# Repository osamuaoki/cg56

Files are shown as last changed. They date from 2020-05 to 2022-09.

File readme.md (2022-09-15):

# Grid Keyboard with 56 keys and its variants
<!---
vim:set tw=79 ts=4 sts=4 sw=4 et nosi filetype=markdown:
-->

This repo hosts data and some documents for my handwared keyboard projects. I
call this repository as cg56 which stands for Cartesian Grid Keyboard with 56
keys.  The corresponding keyboard name in my QMK source is cgc56 which stands
for Cartesian Grid Keyboard (compact) with 56 keys.  The longer name is chosen
to differentiate variants.

## Related memo in Japanese

There are more detailed memos in Japanese on how my hobby project proceeded
slowly since 2016. (Now 2022)  Its highlights are:

* https://osamuaoki.github.io/jp/2020/01/03/cg56-1/
* https://osamuaoki.github.io/jp/2021/12/11/atmega32u4-4/
* https://osamuaoki.github.io/jp/2022/02/07/blackpill-1/
* https://osamuaoki.github.io/jp/2022/03/15/home-mt/
* https://osamuaoki.github.io/jp/2022/09/01/blackpill-4/
* https://osamuaoki.github.io/jp/2022/09/09/home-mt2/ (review)

## Keyboard project history

* cg56: Cartesian Grid Keyboard with 56 keys (2016-2018)
    * NC laser cut MDF board (cut, stacked, glued, filed, and painted)
    * 56 keys (14 x 4)
    * ATMega32u4 x 1 (teensy 2 compatible board with nanoBoot HID bootloader)
    * Project stalled and case is repurposed for the next cgc56 project.
    * [NC CAD data (dxf) is in this repository](cad/cg56.dxf)
    * [NC CAD data (pdf) is in this repository](cad/MDF_CUT_grid56w.pdf)
    * See [ATmega32u4 (rev01)](rev01.md) -- never made -- for details of around MCU and shape of key matrix.
    * See [Key matrix for cg56 and cgc56](cg56.md) for electrical details of key matrix.

* cgc56: Cartesian Grid Keyboard (compact) with 56 keys (2022/Feb -- initial)
    * NC laser cut MDF board
      * recycled case taken from stalled cg56
      * Add independent USB connector board.
      * internal space of already built case was enlarged by mechanically grinding the MDF board
    * 56 keys (14 x 4)
    * AT90USB1286 x 1
      * Teensy 2++ compatible circuit board with LUFA HID bootloader
    * initial cgc56 front view with OEM keycaps
      <br>
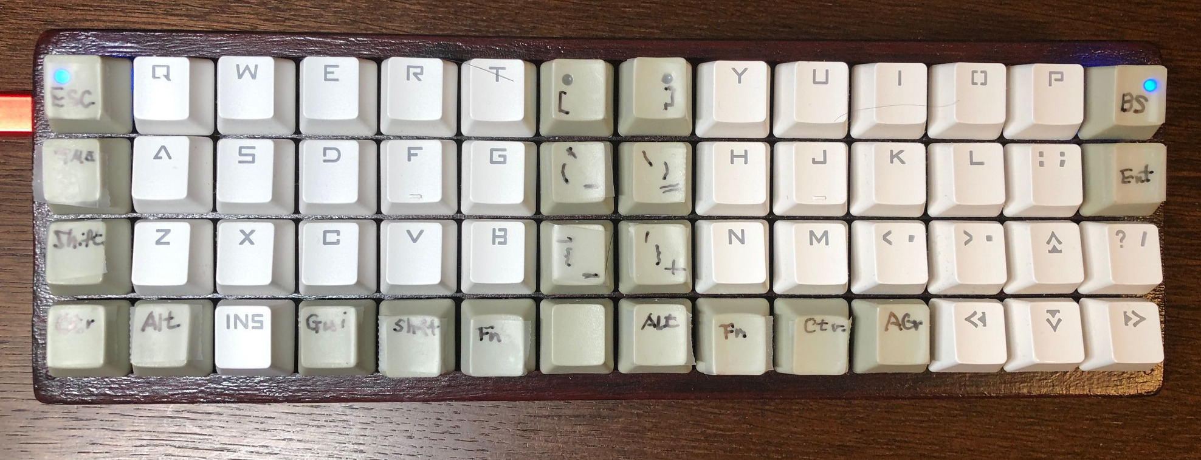
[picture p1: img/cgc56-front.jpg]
      
    * cgc56 side view with OEM key caps
      <br>
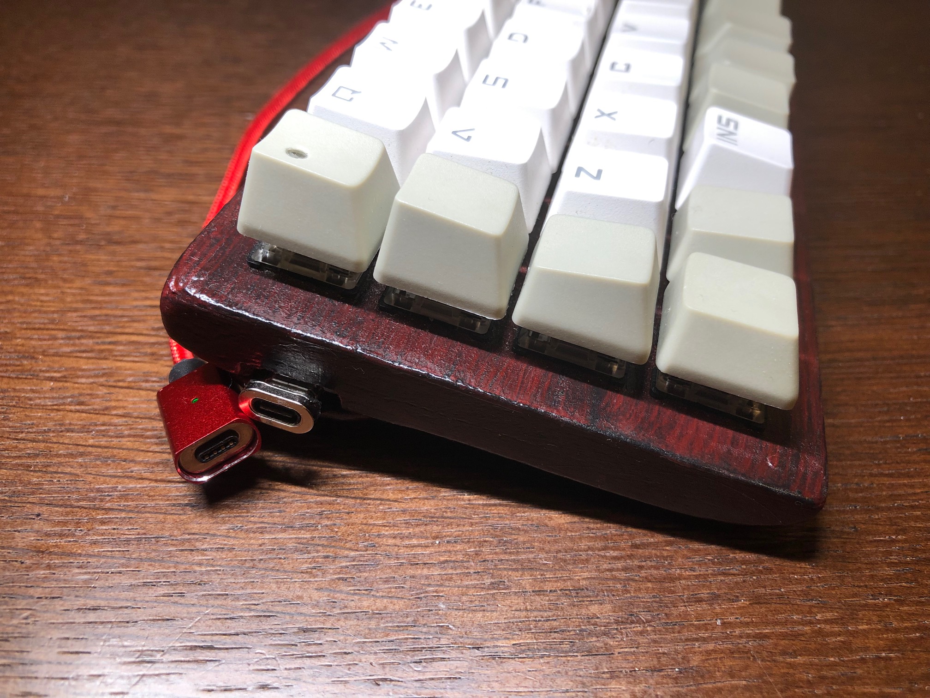
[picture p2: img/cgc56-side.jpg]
      
    * See [AT90USB1286 (rev02)](rev02.md) for details of around MCU and shape of key matrix.
    * See [Key matrix for cg56 and cgc56](cg56.md) for electrical details of key matrix.
    * See [cgc56 in Osamu's QMK fork with osamu1 branch](https://github.com/osamuaoki/qmk_firmware/blob/osamu1/keyboards/cgc56/keymaps/default/keymap.c)  -- this is not maintained.
    * See [extra photo for cg56](photo-cg56.md)

* **cgc56**: Cartesian Grid Keyboard (compact) with 56 keys (2022/Sep)
    * Keycaps are changed to DSA.
      * The front edge of red keycaps for the thumb are rounded using the sand
        paper.
      * keymaps are optimized (now "pico" is used)
    * 56 keys (14 x 4) -- no change
    * AT90USB1286 x 1 -- no change
      <br>
    * updated cgc56 top view with DSA keycaps for the pico keymap
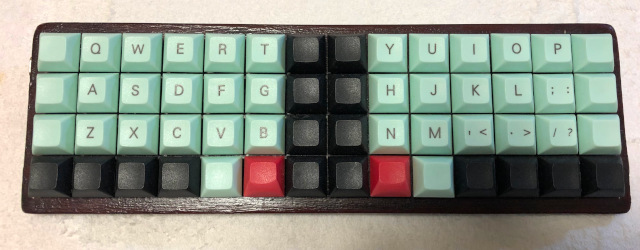
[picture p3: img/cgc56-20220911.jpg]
cgc56 new
      
    * See [cgc56 in Osamu's QMK fork with osamu1 branch](https://github.com/osamuaoki/qmk_firmware/blob/osamu1/keyboards/cgc56/keymaps/pico/keymap.c) -- this is maintained.

* cgg56: Cartesian Grid Keyboard (gap) with 56 keys (2022/Feb)
    * Hand cut and glued 5mm x 5mm plastic bars
    * 56 keys (14 x 4) + X-Y joystick (resistive)
    * STM32F411CE x 1 (WeAct Blackpill)
    * cgg56 front view with OEM keycaps
      <br>
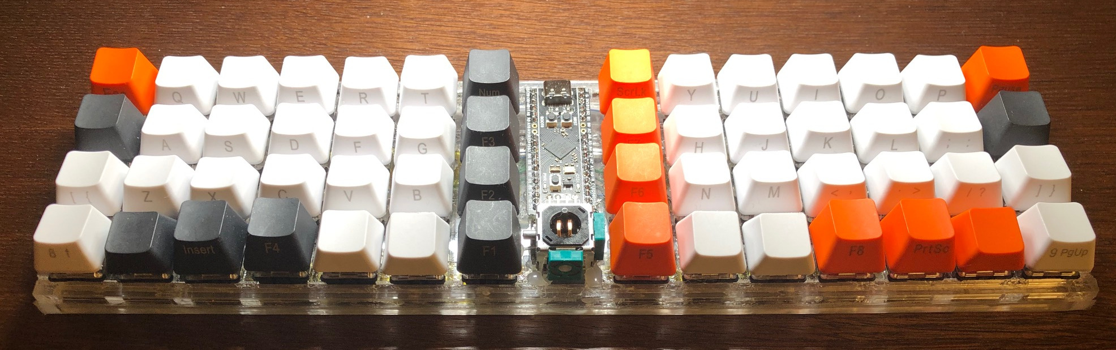
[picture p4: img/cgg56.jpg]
      
    * See [STM32F411CEU6 (rev03)](rev03.md) for details of around MCU and shape of key matrix.
    * See [Key matrix for gcg56](cgg56.md) for electrical details of key matrix.
    * See [STM32F411CE (1)](https://osamuaoki.github.io/jp/2022/02/07/blackpill-1/) (Japanese) for cgg56
    * See [cgg56 in Osamu's QMK fork with osamu1 branch](https://github.com/osamuaoki/qmk_firmware/blob/osamu1/keyboards/cgg56/keymaps/pico/keymap.c) -- this is not maintained.

* cgs58: Cartesian Grid Keyboard (split) with 58 keys
    * Hand cut and glued 5mm x 5mm plastic bars
      * recycled case taken from cgg56
      * hack sawed cgg56 at the center and extended with glued 5mm x 5mm plastic bars
    * 58 keys ((7 x 4 + 1) x 2)
    * STM32F411CE x 2 (WeAct Blackpill)
    * cgs58 front view with OEM keycaps
      <br>
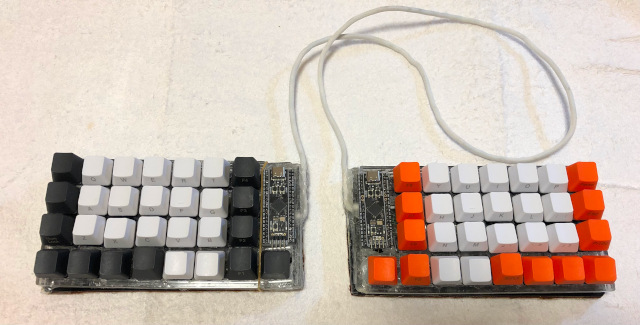
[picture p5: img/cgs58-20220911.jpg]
      
    * This is 16U wide and can't fit into A4 size case. (Too big!)
    * See [STM32F411CE (4)](https://osamuaoki.github.io/jp/2022/09/01/blackpill-4/) (Japanese) for the modification from cgg56 to cgs58.
    * See [cgs58 in Osamu's QMK fork with osamu1 branch](https://github.com/osamuaoki/qmk_firmware/blob/osamu1/keyboards/cgs58/keymaps/pico/keymap.c) -- this is not maintained.

* **cgs50**: Cartesian Grid Keyboard (split) with 50 keys (2022/Sep)
    * Hand cut and glued 5mm x 5mm plastic bars
      * recycled case taken from cgs58
      * hack sawed cgs58 at the both ends and glued 5mm x 5mm plastic bars to close the ends.
    * 50 keys ((6 x 4 + 1) x 2)
    * STM32F411CE x 2 (WeAct Blackpill)
    * cgs50 front view with OEM keycaps
      <br>
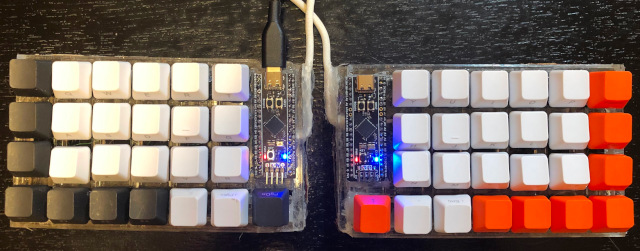
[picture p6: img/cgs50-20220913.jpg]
      
    * This is 14U wide and can fit into A4 size case.
    * Just cut both ends and removed wiring around them.
    * See [cgs58 in Osamu's QMK fork with osamu1 branch](https://github.com/osamuaoki/qmk_firmware/blob/osamu1/keyboards/cgs50/keymaps/pico/keymap.c) -- this is maintained.

## Background

I felt pain between my right ring and pinkie fingers.  I wondered why I suffer
such a pain since I type very slowly and my slow typing should be very low
stress on my fingers.  I then realized that I stretch my pinkie finger to reach
"Enter" and "BS" keys which are away from the home position of my right pinkie
finger.  Situation with laptop JIS (JA) keyboard which I now use regularly is
worse than ANSI (US) keyboard since the "Enter" key is 3 steps away.

Even on the ANSI (US) 104 keyboard, my weak right pinkie finger is covering 20
keys while even my capable right pointer finger covers only 9 keys and most
other fingers cover less.  Although these extra keys typed by my right pinkie
finger are mostly rarely typed keys, these are used more for coding programs.

Also, un-natural staggered key arrangement is another annoyance to twist my
body.  The default positions of hands seem to be too close to each other for me
to keep my good posture.

Hmmm... I need to keep my posture right while keeping my fingers relaxed.

## Design Policy

The following design policy is deployed to design a custom keyboard.

* Use only FREE software (DFSG compliant)
* Compact, simple, and natural design
    * Compact enough to be portable: 56 keys (4 rows x 14 columns) or less
    * Keys in the linear orthogonal Cartesian grid coordinate positions
    * Never move pinkie fingers more than one column away.
    * Never move pointer fingers more than two column away.
    * Keep left and right fingers separated enough.
    * All ASCII codes are accessible without moving the palm position.
* Least leaning pain key-position design
    * Minimal key-position change from the standard ANSI (US).
    * BS at the right top corner.
    * ESC in place of CapsLock position (yay, Vim).
    * Keep F and J keys separated with 4 keys (or more) instead of standard 2 keys.
    * Move non-shift non-alphabet symbols to the center if you ever have them.
    * Layer changing Fn keys in thumb home positions to offer practically all ANSI 104 (JIS 106?) keys.
        * Function keys (F1-F12) are in the top row with Fn.
        * Number keys are in the high-middle row with Fn.
        * Odd keys are in the low-middle row with Fn
    * SPACE should be at the thumb position of the bottom row.
    * Cursor keys are in the hard to reach part of the bottom row if you ever have them.
    * Topography effects to find finger home positions
      * Use key cap height differences with the OEM keycaps.
      * Use mechanically modified thumb keys with DSA keycaps.
* Keep it simple and cheap (It's my first custom keyboard!)
    * Use commodity electronics parts (as much)
      * Use the laser cut MDF board as the case (if needed)
      * Use 5mm x 5mm plastic bars and glue purchased at the local hardware
        shop.
    * Use only 1U key caps (=no stabilizer)
    * No PCB but lots of messy hand wiring :-)

## What's different

You may wonder what's different from other so called "ortholinear" keyboards
such as plank.

* Enough distance between left and right hands. (2U->4U)
* 7 columns per one side instead of 6 columns such as
  [plunk](https://olkb.com/planck) to minimize key position irregularities.
* Single piece compact design without irregular shape vs.
  [Ergo42](https://bit-trade-one.co.jp/selfmadekb/adskb42/) and
  [ErgoTravel](https://github.com/jpconstantineau/ErgoTravel) .
* Extensive use of hot-melt glue which should also function as noise dumper.

Yah, it's not much different in basic hardware design ... it's mostly a taste
difference.

As for the pinkie finger stress, the home row mod keymap really helped.

## Design thoughts

Here, ASCII art versions of basic design implementation ideas are provided.

### Case Design for cg56

Case with orthogonal key switch matrix design with enough space for thumb
finger coverage and without stressing pinkie finger.

* Primary positions: `###` (home positions)
* Almost primary positions: `.#.` (almost home positions)
* Adjacent positions: `...` (easy to reach minimum movement positions)

```
┌───┬───┬───┬───┬───┬───┬───┬───┬───┬───┬───┬───┬───┬───┐
│   │...│...│...│...│...│   │   │...│...│...│...│...│   │
├───┼───┼───┼───┼───┼───┼───┼───┼───┼───┼───┼───┼───┼───┤
│...│###│###│###│###│...│...│...│...│###│###│###│###│...│
├───┼───┼───┼───┼───┼───┼───┼───┼───┼───┼───┼───┼───┼───┤
│...│.#.│...│...│.#.│...│...│...│...│.#.│...│...│.#.│...│
├───┼───┼───┼───┼───┼───┼───┼───┼───┼───┼───┼───┼───┼───┤
│...│...│   │   │...│###│...│...│###│...│   │   │...│...│
└───┴───┴───┴───┴───┴───┴───┴───┴───┴───┴───┴───┴───┴───┘
```

### Key Assignment

Use least surprise design based on the standard QWERTY-keyboard.

Here is an example of key assignment.

Initial thought:
```
default
┌───┬───┬───┬───┬───┬───┬───┬───┬───┬───┬───┬───┬───┬───┐
│TAB│ q │ w │ e │ r │ t │ [ │ ] │ y │ u │ i │ o │ p │BS │
├───┼───┼───┼───┼───┼───┼───┼───┼───┼───┼───┼───┼───┼───┤
│ESC│ a │ s │ d │ f │ g │ ` │ \ │ h │ j │ k │ l │ ; │ ' │
├───┼───┼───┼───┼───┼───┼───┼───┼───┼───┼───┼───┼───┼───┤
│Sft│ z │ x │ c │ v │ b │***│***│ n │ m │ , │ . │ / │Sft│
├───┼───┼───┼───┼───┼───┼───┼───┼───┼───┼───┼───┼───┼───┤
│Ctr│Alt│ ↑ │ ↓ │Gui│Fn │Spc│Ent│Fn │App│ ← │ → │Alt│Ctr│
└───┴───┴───┴───┴───┴───┴───┴───┴───┴───┴───┴───┴───┴───┘

Fn-pressed
┌───┬───┬───┬───┬───┬───┬───┬───┬───┬───┬───┬───┬───┬───┐
│Prt│F1 │F2 │F3 │F4 │F5 │F11│F12│F6 │F7 │F8 │F9 │F10│SL │
├───┼───┼───┼───┼───┼───┼───┼───┼───┼───┼───┼───┼───┼───┤
│Cap│ 1 │ 2 │ 3 │ 4 │ 5 │ - │ = │ 6 │ 7 │ 8 │ 9 │ 0 │PB │
├───┼───┼───┼───┼───┼───┼───┼───┼───┼───┼───┼───┼───┼───┤
│___│***│***│***│***│***│***│***│***│***│***│***│***│___│
├───┼───┼───┼───┼───┼───┼───┼───┼───┼───┼───┼───┼───┼───┤
│___│___│Hom│End│Alt│___│Ins│Del│___│Ctl│PgU│PgD│___│___│
└───┴───┴───┴───┴───┴───┴───┴───┴───┴───┴───┴───┴───┴───┘
```

[Current QMK setting: (2022/Sep)](https://github.com/osamuaoki/qmk_firmware/blob/osamu1/keyboards/cgc56/keymaps/pico/keymap.c)
 -- with many tap-hold dual function keys.
```
0th layer: Normal tap (Essential stable keys only)
┌───┬───┬───┬───┬───┬───┬───┬───┬───┬───┬───┬───┬───┬───┐
│Tab│ Q │ W │ E │ R │ T │   │   │ Y │ U │ I │ O │ P │BS │
├───┼───┼───┼───┼───┼───┼───┼───┼───┼───┼───┼───┼───┼───┤
│Esc│ A │ S │ D │ F │ G │   │   │ H │ J │ K │ L │ ; │Ent│
├───┼───┼───┼───┼───┼───┼───┼───┼───┼───┼───┼───┼───┼───┤
│Mut│ Z │ X │ C │ V │ B │   │   │ N │ M │ , │ . │ / │Psc│
├───┼───┼───┼───┼───┼───┼───┼───┼───┼───┼───┼───┼───┼───┤
│   │   │   │   │MUH│Spc│   │   │Spc│HEN│   │   │   │   │
└───┴───┴───┴───┴───┴───┴───┴───┴───┴───┴───┴───┴───┴───┘

0th layer: Normal hold (MOD and LAYER keys)
┌───┬───┬───┬───┬───┬───┬───┬───┬───┬───┬───┬───┬───┬───┐
│   │   │   │   │   │   │   │   │   │   │   │   │   │   │
├───┼───┼───┼───┼───┼───┼───┼───┼───┼───┼───┼───┼───┼───┤
│Ctl│Sft│Crl│Alt│Gui│Agr│   │   │Agr│Gui│Alt│Ctl│Sft│   │
├───┼───┼───┼───┼───┼───┼───┼───┼───┼───┼───┼───┼───┼───┤
│Sft│   │   │Gui│MO2│   │   │   │   │   │   │   │   │Sft│
├───┼───┼───┼───┼───┼───┼───┼───┼───┼───┼───┼───┼───┼───┤
│   │   │   │   │   │   │   │   │   │   │   │   │   │   │
└───┴───┴───┴───┴───┴───┴───┴───┴───┴───┴───┴───┴───┴───┘

1st layer: activate with one Fn-key (= space key) pressed as hold
┌───┬───┬───┬───┬───┬───┬───┬───┬───┬───┬───┬───┬───┬───┐
│F11│F1 │F2 │F3 │F4 │F5 │   │   │F6 │F7 │F8 │F9 │F10│F12│
├───┼───┼───┼───┼───┼───┼───┼───┼───┼───┼───┼───┼───┼───┤
│Cap│ 1 │ 2 │ 3 │ 4 │ 5 │   │   │ 6 │ 7 │ 8 │ 9 │ 0 │App│
├───┼───┼───┼───┼───┼───┼───┼───┼───┼───┼───┼───┼───┼───┤
│   │ ` │   │   │ - │ = │   │   │ { │ } │ \ │   │ ' │LL2│
├───┼───┼───┼───┼───┼───┼───┼───┼───┼───┼───┼───┼───┼───┤
│   │   │   │   │   │vvv│   │   │vvv│KAN│   │   │   │   │
└───┴───┴───┴───┴───┴───┴───┴───┴───┴───┴───┴───┴───┴───┘

```
Please note:

* "shift-pressed" causes the normal shift conversion
* Missing function keys are generated by Fn-pressed Q-row keys.
* Missing number row keys are generated by Fn-pressed A-row keys.
* Missing outlier keys are generated by Fn-pressed Z-row keys.
* Let's worry about details later when in QMK firmware.
* Actual key layout will be experimentally determined.
  * 2nd layer: cursor
  * 3rd layer: ten-keys
  * 4th layer: mouse keys and system control

### Keyboard Topography (Type 1)

OEM 1U Key cap are used as below to offer optimal topography.

```
┌───┬───┬───┬───┬───┬───┬───┬───┬───┬───┬───┬───┬───┬───┐
│*1 │ Q │ Q │ Q │ Q │ Q │*1 │ 1*│ Q │ Q │ Q │ Q │ Q │ 1*│
├───┼───┼───┼───┼───┼───┼───┼───┼───┼───┼───┼───┼───┼───┤
│ 1 │_A_│_A_│_A_│_A_│ A │ 1 │ 1 │ A │_A_│_A_│_A_│_A_│ 1 │
├───┼───┼───┼───┼───┼───┼───┼───┼───┼───┼───┼───┼───┼───┤
│ Z │ Z │ Z │ Z │ Z │ Z │ 1 │ 1 │ Z │ Z │ Z │ Z │ Z │ Z │
├───┼───┼───┼───┼───┼───┼───┼───┼───┼───┼───┼───┼───┼───┤
│ A │ Z │ R │ R │ 1 │_Q_│ 1 │ 1 │_Q_│ 1 │ R │ R │ Z │ A │
└───┴───┴───┴───┴───┴───┴───┴───┴───┴───┴───┴───┴───┴───┘
 1:   1-row type
 Q:   Q-row type
 A:   A-row type
 Z:   Z-row type
 R:   Arrow-keys inserted upside down
 _ _: home position
 *:   LED position (outside is RED LED)
```

With the height difference to the adjacent keys, thumb and pinkie fingers
should have easier time to feel its home position.  (I may change height
combination later.)

Also by deploying higher keys (1-row type) for far-away keys, you can type
these keys by pressing their side faces.  They may not be bigger but are
easy to be reached.

### Keyboard Topography (Type 2)

Alternatively, DSA key tops may be used.

For that, I thought that modifying some keys with soft UV-resin or
crazy-glue+baking-soda may be interesting options to create topography.

I ended up grinding off front edge of thumb keys.

## Sitalled side project -- QWFRTY layout

**QWFRTY** layout was investigated as a minimal learning stress alternative layout but it was not so good.

* **QWFRTY** moves only 11-keys from the standard QWERTY.  Almost all short-cuts stay in place.
* **QWFRTY** encourages alternating hand typing like DVORAK by having all vowel characters on one side.  This should be lower stress.
  **QWFRTY** doesn't trash the user experience under Vim.  `hjkl`-keys are clustered as inverse-T making it even better than QWFRTY.

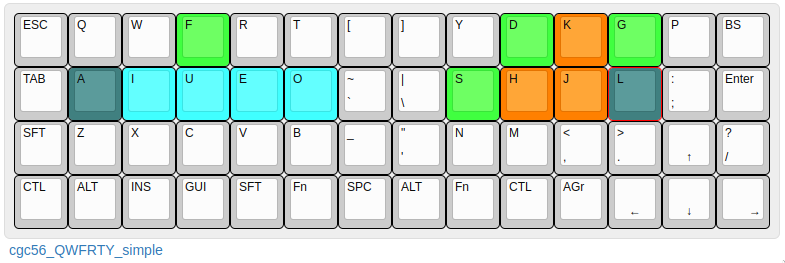
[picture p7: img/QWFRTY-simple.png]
QWFRTY


See https://osamuaoki.github.io/jp/2022/02/14/qwfrty/ (Japanese)

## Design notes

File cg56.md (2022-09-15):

# Key matrix for cg56 and cgc56
<!---
vim:set tw=79 ts=4 sts=4 sw=4 et nosi filetype=markdown:
-->

## Physical and Electrical Key Positions

The electric wiring column and row positions are described as below in
"Column/Row" order in the physical key positions.

Please note:
* Physical matrix: 4 rows * 14 columns
* Electrical matrix: 8 rows * 7 columns

This allows to scan 54 keys only with 15 pins.

### Top view

This top view can be used for software key address configuration.

```
 Q-side (Teensy)                          P-side (Speaker)
 ┌───┬───┬───┬───┬───┬───┬───┬───┬───┬───┬───┬───┬───┬───┐
 │0/0│1/0│2/0│3/0│4/0│5/0│6/0│0/1│1/1│2/1│3/1│4/1│5/1│6/1│
 ├───┼───┼───┼───┼───┼───┼───┼───┼───┼───┼───┼───┼───┼───┤
 │0/2│1/2│2/2│3/2│4/2│5/2│6/2│0/3│1/3│2/3│3/3│4/3│5/3│6/3│
 ├───┼───┼───┼───┼───┼───┼───┼───┼───┼───┼───┼───┼───┼───┤
 │0/4│1/4│2/4│3/4│4/4│5/4│6/4│0/5│1/5│2/5│3/5│4/5│5/5│6/5│
 ├───┼───┼───┼───┼───┼───┼───┼───┼───┼───┼───┼───┼───┼───┤
 │0/6│1/6│2/6│3/6│4/6│5/6│6/6│0/7│1/7│2/7│3/7│4/7│5/7│6/7│
 └───┴───┴───┴───┴───┴───┴───┴───┴───┴───┴───┴───┴───┴───┘
```

This is useful view for writing software for the key input conversion.

### Bottom view

This bottom view can be used for wiring key switches.

```
 P-side (Speaker)                         Q-side (Teensy)
 ┌───┬───┬───┬───┬───┬───┬───┬───┬───┬───┬───┬───┬───┬───┐
 │6/1│5/1│4/1│3/1│2/1│1/1│0/1│6/0│5/0│4/0│3/0│2/0│1/0│0/0│
 ├───┼───┼───┼───┼───┼───┼───┼───┼───┼───┼───┼───┼───┼───┤
 │6/3│5/3│4/3│3/3│2/3│1/3│0/3│6/2│5/2│4/2│3/2│2/2│1/2│0/2│
 ├───┼───┼───┼───┼───┼───┼───┼───┼───┼───┼───┼───┼───┼───┤
 │6/5│5/5│4/5│3/5│2/5│1/5│0/5│6/4│5/4│4/4│3/4│2/4│1/4│0/4│
 ├───┼───┼───┼───┼───┼───┼───┼───┼───┼───┼───┼───┼───┼───┤
 │6/7│5/7│4/7│3/7│2/7│1/7│0/7│6/6│5/6│4/6│3/6│2/6│1/6│0/6│
 └───┴───┴───┴───┴───┴───┴───┴───┴───┴───┴───┴───┴───┴───┘
```

This is useful view for wiring and building the hardware.

## Wiring of Switches and LEDs

This section always uses bottom view unless otherwise noted.

### Global simplified view of wiring

Here is a global simplified view of wiring of switches and LEDs (bottom view):

```
   P-side (Speaker)                                  Q-side (Teensy)

    LED4                      LED3  LED2                       LED1
    RCB                        RCB  RCB                         RCB

    C6  C5  C4  C3  C2  C1  C0            C6  C5  C4  C3  C2  C1  C0
    |   |   |   |   |   |   |             |   |   |   |   |   |   |
    S---S---S---S---S---S---S-- R1  R0  --S---S---S---S---S---S---S
    |   |   |   |   |   |   |             |   |   |   |   |   |   |
    S---S---S---S---S---S---S-- R3  R2  --S---S---S---S---S---S---S
    |   |   |   |   |   |   |             |   |   |   |   |   |   |
    S---S---S---S---S---S---S-- R5  R4  --S---S---S---S---S---S---S
    |   |   |   |   |   |   |             |   |   |   |   |   |   |
    S---S---S---S---S---S---S-- R7  R6  --S---S---S---S---S---S---S

```

Here:
* "+" indicates contacting cross
* "C" indicates no contact over cross
* "S" indicates switch and diode connect cross wire combination
* 2 wires for each column

### Key switches, LEDs, CRDs, Diodes and Speaker (Bottom view)

Insert [2 color LED](img/OSRB3132A.png) as below to the key switches (Bottom view)

```
 6/1, 0/1 switches          5/1, 4/1, 3/1, 2/1, 5/0, 4,0, 3/0, 2/0, 1/0,
                            6/3, 5/3, ..., 1/3, 6/2, 5/2, ..., 1/2, 0/2,
                            6/5, 5/5, ..., 1/5, 6/4, 5/4, ..., 1/4, 0/4
                            switches
  LED  LED  LED                  COL
  R    C    B                     |
 ┌|────|────|──┐                ┌─|───────────┐
 │0->|-0-|<-0  │                │ |           │
 │             │                │ V           │
 │      O      │                │ -    O      │
 │             │                │ |           │
 │ +0          │                │ +0          │
 │ |         0 │                │           0 │
 └─|─────────|─┘                └───────────|─┘
   -         +-- ROW                        +-- ROW
   ^
   +-- COL

  6/0, 0/0 switches          6/7, 5/7, ..., 1/7, 6/6, 5/6, ..., 1/6, 0/6
  are mirror image           switches are flipped orientation

```

* LEDs are inserted to the select 4 top row key switches only
* RED LED side are inserted to the outside
* 0/0 is mirror image of 6/1
* LED inserting side of key switches are pointing to the far-side
* Bottom row flips direction of key switches for the easier pin access
* [CRD](img/CRD.png) is used to limit current to LED.

Use 4 of 3mm RED-BLUE LED after grinding off the bottom rip of LED-resin.

```
     LED    CRD
  +--|<-----|O--- Driver for Blue (inner side) LED?B
  |      (-)  (+)
  +-------------- GND                          LED?C
  |
  +--|<-----|O--- Driver for Red  (outer side) LED?R
                                               ?=1.2.3.4
```

Always anode side (bars printed) of diodes and CRDs are connected to the
switches and CRDs.

Original case for the speaker was removed to make it fit inside.

### Full view of wiring

Here is the full view of wiring as the bottom view

```
    P-side (Speaker)                                                                                                                                                     Q-side (Teensy)

        LED4                                                                     LED3                LED2                                                                      LED1
        RCB                                                                      RCB                 RCB                                                                       RCB
        |||                                                                      |||                 |||                                                                       |||
        A|A                                                                      A|A                 A|A                                                                       A|A
        |+|----------------------------------------------------------------------|+|--------+--------|+|-----------------------------------------------------------------------|+|
        | |                                                                      | |        |        | |                                                                       | |
                                                                                           GND

    X-----------X-----------X------------X-----------X-----------X-----------X------------+   +----X-----------X-----------X------------X-----------X-----------X-----------X---------
            X           X            X           X           X           X           X    |   |            X           X            X           X           X           X           X
            |           |            |           |           |           |           |    R1  R0           |           |            |           |           |           |           |
        C6  A       C5  A       C4   A       C3  A       C2  A       C1  A       C0  A                 C6  A       C5  A       C4   A       C3  A       C2  A       C1  A           A
        |   |       |   |       |    |       |   |       |   |       |   |       |   |                 |   |       |   |       |    |       |   |       |   |       |   |       |   |
        +---+       +---+       +----+       +---+       +---+       +---+       +---+                 +---+       +---+       +----+       +---+       +---+       +---+       +---+
        |   |       |   |       |    |       |   |       |   |       |   |       |   |                 |   |       |   |       |    |       |   |       |   |       |   |       |   |
        |   V       |   V       |    V       |   V       |   V       |   V       |   V                 |   V       |   V       |    V       |   V       |   V       |   V       |   V
        |   |       |   |       |    |       |   |       |   |       |   |       |   |                 |   |       |   |       |    |       |   |       |   |       |   |       |   |
    X---C---C---X---C---C---X---C----C---X---C---C---X---C---C---X---C---C---X---C---C----+   +----X---C---C---X---C---C---X---C----C---X---C---C---X---C---C---X---C---C---X---C---C-
        |   |       |   |       |    |       |   |       |   |       |   |       |   |    |   |        |   |       |   |       |    |       |   |       |   |       |   |       |   |
        |   X       |   X       |    X       |   X       |   X       |   X       |   X    R3  R2       |   X       |   X       |    X       |   X       |   X       |   X       |   X
        |           |           |            |           |           |           |                     |           |           |            |           |           |           |
        |           |           |            |           |           |           |                     |           |           |            |           |           |           |
        |           |           |            |           |           |           |                     |           |           |            |           |           |           |
    X---C-------X---C-------X---C--------X---C-------X---C-------X---C-------X---C--------+   +----X---C-------X---C-------X---C--------X---C-------X---C-------X---C-------X---C-----
        |   X       |   X       |    X       |   X       |   X       |   X       |   X    |   |        |   X       |   X       |    X       |   X       |   X       |   X       |   X
        |   |       |   |       |    |       |   |       |   |       |   |       |   |    R5  R4       |   |       |   |       |    |       |   |       |   |       |   |       |   |
        |   A       |   A       |    A       |   A       |   A       |   A       |   A                 |   A       |   A       |    A       |   A       |   A       |   A       |   A
        |   |       |   |       |    |       |   |       |   |       |   |       |   |                 |   |       |   |       |    |       |   |       |   |       |   |       |   |
        +---+       +---+       +----+       +---+       +---+       +---+       +---+                 +---+       +---+       +----+       +---+       +---+       +---+       +---+
            |           |            |           |           |           |           |                     |           |            |           |           |           |           |
            V           V            V           V           V           V           V                     V           V            V           V           V           V           V
            |           |            |           |           |           |           |    R7  R6           |           |            |           |           |           |           |
            X           X            X           X           X           X           X    |   |            X           X            X           X           X           X           X
    X-----------X-----------X------------X-----------X-----------X-----------X------------+   +----X-----------X-----------X------------X-----------X-----------X-----------X---------
```

Here:
* "+" indicates contacting cross
* "C" indicates no contact over cross
* "X" indicates switch terminal soldering
* "A" and "V" are meant to be diode (up/down arrow).
* ".." are meant to be long distance wiring

Please note above schematics are there to understand the thought behind
my wiring design.  The photo provides the most accurate record of my
wiring.

Case has glued micro USB port on PCB (2.54mm pitch converter) which has very
short line to male mini-USB-B connector (created by cutting mini-USB cable).
This mini-USB connector should trim its plastic moldings as much to avoid
physical interference.

USB cabling (mini-USB 4 wire line w/o sealed)
Pin	Name	Wire color[a]	Description
1	VBUS	Red or	Orange	+5 V
2	D−	White or	Gold	Data−
3	D+	Green	Data+
4	GND	Black or	Blue	Ground

My cable (cut and opened)
black -- GND
green -- D+
white -- D-
red   -- VBUS/5V

Caveat:
Due to maximum current draw per chip, never turn on more than 4 LEDs.

Reset button is hard to reach without opening the case due to change from
Teensy2.0 type board to Teensy2.0++ type one for more memory space.  For this,
make sure to create a "Quantum Keycode: RESET" to enable bootloader from
keyboard.

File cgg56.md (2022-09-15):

# Key matrix for gcg56
<!---
vim:set tw=79 ts=4 sts=4 sw=4 et nosi filetype=markdown:
-->

## Physical and Electrical Key Positions

The electric wiring column and row positions are described as below in
"Column/Row" order in the physical key positions.

Please note:
* Physical matrix: 4 rows * 14 columns
* Electrical matrix: 4 rows * 14 columns

This allows to scan 54 keys only with 18 pins.

### Top view

This top view can be used for software key address configuration.

```
 Q-side                                                P-side
 ┌───┬───┬───┬───┬───┬───┬───┬───┬───┬───┬───┬───┬───┬───┬───┐
 │0/0│1/0│2/0│3/0│4/0│5/0│6/0│USB│7/0│8/0│9/0│A/0│B/0│C/0│D/0│
 ├───┼───┼───┼───┼───┼───┼───┤   ├───┼───┼───┼───┼───┼───┼───┤
 │0/1│1/1│2/1│3/1│4/1│5/1│6/1│   │7/1│8/1│9/1│A/1│B/1│C/1│D/1│
 ├───┼───┼───┼───┼───┼───┼───┤MCU├───┼───┼───┼───┼───┼───┼───┤
 │0/2│1/2│2/2│3/2│4/2│5/2│6/2│   │7/2│8/2│9/2│A/2│B/2│C/2│D/2│
 ├───┼───┼───┼───┼───┼───┼───┤   ├───┼───┼───┼───┼───┼───┼───┤
 │0/3│1/3│2/3│3/3│4/3│5/3│6/3│   │7/3│8/3│9/3│A/3│B/3│C/3│D/3│
 └───┴───┴───┴───┴───┴───┴───┴───┴───┴───┴───┴───┴───┴───┴───┘
```

This is useful view for writing software for the key input conversion.

### Bottom view

This bottom view can be used for wiring key switches.

```
 P-side                                                Q-side
 ┌───┬───┬───┬───┬───┬───┬───┬───┬───┬───┬───┬───┬───┬───┬───┐
 │D/0│C/0│B/0│A/0│9/0│8/0│7/0│USB│6/0│5/0│4/0│3/0│2/0│1/0│0/0│
 ├───┼───┼───┼───┼───┼───┼───┤   ├───┼───┼───┼───┼───┼───┼───┤
 │D/1│C/1│B/1│A/1│9/1│8/1│7/1│   │6/1│5/1│4/1│3/1│2/1│1/1│0/1│
 ├───┼───┼───┼───┼───┼───┼───┤MCU├───┼───┼───┼───┼───┼───┼───┤
 │D/2│C/2│B/2│A/2│9/2│8/2│7/2│   │6/2│5/2│4/2│3/2│2/2│1/2│0/2│
 ├───┼───┼───┼───┼───┼───┼───┤   ├───┼───┼───┼───┼───┼───┼───┤
 │D/3│C/3│B/3│A/3│9/3│8/3│7/3│   │6/3│5/3│4/3│3/3│2/3│1/3│0/3│
 └───┴───┴───┴───┴───┴───┴───┴───┴───┴───┴───┴───┴───┴───┴───┘
```

This is useful view for wiring and building the hardware.

## Wiring of Switches

This section always uses bottom view unless otherwise noted.

### Global simplified view of wiring

Here is a global simplified view of wiring of switches (bottom view):

```
 P-side                                                Q-side

        CD  CC  CB  CA  C9  C8  C7    C6  C5  C4  C3  C2  C1  C0
        C13 C12 C11 C10 C9  C8  C7    C6  C5  C4  C3  C2  C1  C0
        |   |   |   |   |   |   | USB |   |   |   |   |   |   |
  R0  --S---S---S---S---S---S---S-----S---S---S---S---S---S---S
        |   |   |   |   |   |   |     |   |   |   |   |   |   |
  R1  --S---S---S---S---S---S---S-----S---S---S---S---S---S---S
        |   |   |   |   |   |   |     |   |   |   |   |   |   |
  R2  --S---S---S---S---S---S---S-----S---S---S---S---S---S---S
        |   |   |   |   |   |   |     |   |   |   |   |   |   |
  R3  --S---S---S---S---S---S---S-----S---S---S---S---S---S---S

```

Here:
* "+" indicates contacting cross
* "C" indicates no contact over cross
* "S" indicates switch and diode connect cross wire combination
* 2 wires for each column

### Key switches and Diodes

```
               COL
                |
    ┌───────────|─┐
  ----------\   | │  /--
    │ +->|---+--^---+
    │ |    O    | │
    │ |         | │
    │ +0        | │
    │           0 │
    └───────────|─┘
```

Please note above schematics are there to understand the thought behind
my wiring design.  The photo provides the most accurate record of my
wiring.

### MCU

Some pin-header are soldered to Blackpill board.  From USB side: P1-P6, P9-P-last (skip 2 pins)
Removals of some pins were needed to avoid interference with case.

## Joystick

Since there were empty space at the center near your thums, I decided add
X-Y potentiometer and wired to analog pins.

See [Joystick Support](https://osamuaoki.github.io/jp/2022/04/02/joystick/) (Japanese).

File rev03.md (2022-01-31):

# gcg56: STM32F411CEU6 (rev03)
<!---
vim:set tw=79 ts=4 sts=4 sw=4 et nosi filetype=markdown:
-->

ARM based Blackpill board with STM32F411CEU6 offers bigger memory than AVR
based TEENSY 2.0 and TEENSY 2.0++ boards.

## Case Design

This is an alternative case design for a custom ortholinear keyboard case which
doesn't rely on accessibility to the high precision NC laser-cut nor milling
tools.  This uses commodity 5x5 mm square plastic rods, glue, rasp (file), and
the hand saw. (I use acrylic rods but ABS or hardwood bar should work too.)

The base size of
KB-SW is about 14.5 x 14 mm and 5mm rods work nicely to realize the standard 19
mm KB pitch.

### Step 1:
Cut 5mmx5 mm rods into following length (mm) with the hand saw:

```
TOP
 size    pcs
  295      2 (outside)
   75     14
   12     42

BTM
 size    pcs
  285      2 (outside)
  285      2 (inside) -- make groove for wire paths
   85      2 (outside)

PWB gap ------  18 (~ 7 pitch)  -- this was for Teansy 2.0++

BTM Plate -- ~ 290 x 80 mm

```
Here, theoretically center gap for PWB should be 19 mm (`= 295 - 14 * 19 - 10 =
276, 295 - 276`) if horizontal key spacing is exactly 19mm.  Actual center gap
is 18mm (1mm lost in extra spaces consumed over 14 key switches).  18mm is
enough for Teensy 2.0 ++ PCB (2.54x7=17.78 mm wide) to fit inside but blackpill
is wider (2.54x8=20.32 mm wide).

Also, vertical spacing is 20mm (`=(75+5)/4`mm).  These extra spaces are needed
to absorb machining variations of the sloppy manual assembly.

Blackpill PCB seems to be 2.54mm wider than Teansy 2.0++ but PIN gaps are at
the same.  This makes Blackpill PCB to sit on case bars while PINs are snug
between bars.

(Please make sure to keep the length of rods as exact as possible.)

### Step 2:

Glue BTM square 285-83-285-83 (solvent) while holding them to flat surface
with masking tapes.  Exact shape is essential.

### Step 3:

Glue TOP square 73-295-73 (solvent) while stacking exactly onto the BTM
square.  Keep 295 temporary fixed by tape.  Grooves are all facing inward of
the square.)

### Step 4:

Set up some KB-SWs using 75s as spacer and glue 75s (solvent type)
After these, glue the non-glued 295.

### Step 5:
Place all KB-SWs, tape fix them, and flip.  Glue 12s as spacer and glue them
(solvent type)

### Step 6:

Place 7s (6-8 pics) at some cross points in side way and glue (solvent type).
(Leave some space for LED back light)

### Step 7:
Place PCB with socket and joy stick on center back and glue. (solvent type)

### Step 8:

Glue KB-SWs (hot melt type) for stability (remove tape)

### Step 9:

Round the bottom and side edges using rasp.

## Step 10:

Add pin header to blackpill (with 2 pins removed from each side to avoid
mechanical interference.)

## Step 11:

Wire! and program!

### Step 99:

Use thin double sided tape to close bottom with plate with leather glued on it.

## Wiring of MCU

The MCU board is placed at the center of the key matrix.

Top view of Blackpill board:

```
Q-side                       USB-C                    P-side
                        +---+-----+---+
                25  B12 |*  |     |  *| 5V
                26  B13 |*  |     |  *| GND
                27  B14 |*  |     |  *| 3V3
                28  B15 |*  +-----+  *| B10 21
                29  A8  |*           @| B2  20   BOOT1
                30  A9  |*  B     N  @| B1  29   ADC9
XX              31  A10 |*  O     R  @| B0  18
XX              32  A11 |*  O     S  @| A7  17
                33  A12 |*  T     T  *| A6  16
                38  A15 |*  0        *| A5  15
                39  B3  |*           *| A4  14
                40  B4  |*           *| A3  13
                41  B5  |*           *| A2  12
                42  B6  |*           *| A1  11
                43  B7  |*           *| A3  10   ADC0
                45  B8  |*  P        *| R    7   NRST
                46  B9  |*  W        *| C15  4
                    5V  |*  R        *| C14  3
                    GND |*           *| C13  2   LED(Blue)
                    3V3 |*  @ @ @ @  *| VB   1
                        +-------------+
                            ^ ^ ^ ^
                            | | | |
        3V3   --------------+ | | |
    34  DIO   ----------------+ | |
    37  SCK   ------------------+ |
        GND   --------------------+

BOOT1: pull down to ground to enable DFU mode. (10K?)

```
The pin names used here are ones for STM32F411CEU6 chip.

Here, the Blackpill board has:
* 44 total PINs
* 11 non-IO PINs
* 33 digital I/O pins
* 10 analog 12bit DAC pins

There are 31 I/O needs under normal usage:
* 4 rows of keyboard switches (input)
* 14 columns of keyboard switches (output)

This can be implemented as:

* DIODE_DIRECTION COL2ROW (Column as input side)
* ROW[0:3] =      { B12, B13, B14, B15 }      (write) - Cathode
* Column[0:13] =  { A8, A9, A12, A15, B3, B4, B5, B6, B7, B8, B9, C14, C15, B10 }     (read) - Anode

#### MCU to Parts

For easier wiring, let's recap as a counter clockwise mapping for the MCU
board. (MCU at the center:

The pin names usage here are ones for STM32F411CEU6 chip.

Pin order from USB connector side:

* Anti-clock wise: Top view
* Clock wise: Bottom view

| MCU | Parts | Note |I/O|
|-----|---|---|---|
| B12 | R0 | `Q`-row | O | Q-side
| B13 | R1 | `A`-row | O |
| B14 | R2 | `Z`-row | O |
| B15 | R3 | bottom row | O |
| A8  | C0 | `Tab`-column | I |
| A9  | C1 | `Q`-column | I |
| A10 | | NO PIN | |
| A11 | | NO PIN | |
| A12 | C2 | `W`-column | I |
| A15 | C3 | `E`-column | I |
| B3  | C4 | `R`-column | I |
| B4  | C5 | `T`-column | I |
| B5  | C6 | `[`-column | I |
| B6  | C7 | `]`-column | I |
| B7  | C8 | `Y`-column | I |
| B8  | C9 | `U`-column | I |
| B9  | C10 | `I`-column | I |
| 5V  | | | |
| GND | | | |
| 3V3 | | | |
| 3V3 | | Edge * * | |
| DIO | | Edge * * | |
| SCK | | Edge * * | |
| GND | | Edge * * | |
| VB  | | | |
| C13 | | internal LED | O |
| C14 | C11 | `O`-column | I |
| C15 | C12 | `P`-column | I |
| RST | NRST | * * | * |
| A3  | ADC0 | (Joystick) | |
| A4  | ADC1 | (Joystick) | |
| A5  | ADC2 | | |
| A6  | ADC3 | | |
| A7  | ADC4 | | |
| A8  | ADC5 | | |
| A9  | ADC6 | | |
| A10 | ADC7 | NO PIN | |
| B0  | ADC8 | NO PIN | |
| B1  | ADC9 | | |
| B2  | BOOT1 | (10K to GND) | |
| B10 | C13 | `BS`-column | I |
| 3V3 | VCC | * * | * |
| GND | GND | * * | O |
| 5V  | NC | * * | |P-side

ADC-pins will be used for joystick (optional).

#### MCU firmware

Use DFU

### Guide for the wiring steps

1. Test MCU board by programming via DFU mode with blink LED on PD6 using
   dfu-util.

1. All 56 key switches are placed into the keyboard case.  I used hot-melt glue
   to hold loose switches.  Please don't overdo it.  You can always add more
   glue after everything is completed to ensure the mechanical integrity of the
   keyboard.

1. Then the wiring of rows are done using anode-side lead wires of diode with
   each cathode-side lead wire connected to each switch.  The right and left
   side of anode-side leads are connected.  This makes total of 4 AWG30 wires
   for the row signal. (Column to row configuration)

1. Then the wiring of columns are done using short UEW AWG32 wires.  One AWG30
   wire is soldered for each column.  This makes total of 14 AWG30 wires for
   the column signal.

1. Use tester to check keyboard connections in ohm mode.  (Please note that, in
   ohm mode of modern multimater, diode appears as insulator for both
   directions.)

1. Use tester to check forward and reverse voltage drop across each diode to be
   around 0.5V-0.6V and OL (over-range) to make sure each diode pointing the
   right direction and not shorted.  It is easy to overlook the cathode
   marking.

1. Secure position of MCU with the hot-melt glue to the case.

1. Connect MCU board to parts with wire-wrapping.

1. Connect USB-C connector to MCU board.

## BOM

The following reference prices are rough US$ figures for the baseline
estimates.  Expect to drop about $150 which is more than a typical gaming
mechanical keyboards.  It ain't cheap but it's fun!!!

* 1 x Blackpill                         --  $7
* 1 x USB-C cable
* Gateron Brown+white switches          --  $30
* Blank PBT 87 keycaps (ebay)           --  $20
* Diode IN4148 equiv. (100 piece pack)  --  $ 2
* AWG30 multi color set                 --  $ 5
* UEW AWG32 wire                        --  $ 5?
* Hot melt glue and glue gun            --  $10 (?)
* Solders, circuit tester, ...

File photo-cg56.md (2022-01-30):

# Photo for cg56
<!---
vim:set tw=79 ts=4 sts=4 sw=4 et nosi filetype=markdown:
-->

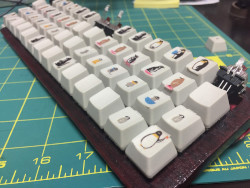
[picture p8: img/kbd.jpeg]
kbd
* Keyboard as it built with LEDs 
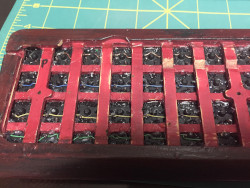
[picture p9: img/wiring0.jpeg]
step 0
* wiring in progress (step 0) 
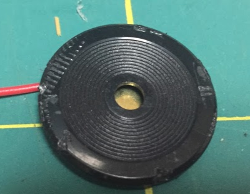
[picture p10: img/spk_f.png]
spk_f
* Front side of speaker 
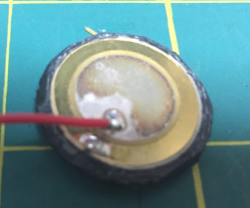
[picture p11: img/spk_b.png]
spk_b
* Back side of speaker 

Original case for the speaker was removed to make it fit inside.

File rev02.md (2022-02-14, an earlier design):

# cg56: AT90USB1286 (rev02)
<!---
vim:set tw=79 ts=4 sts=4 sw=4 et nosi filetype=markdown:
-->

TEENSY 2.0++ type board with AT90USB1286 offers bigger memory than TEENSY 2.0
type board with ATmega32u4.  When I bought an inexpensive TEENSY 2.0++
compatible board, I decided to switch this project to use it.

## Case Design

LibreCAD was used to create DXF (drawing exchange format) file for case.

* [Keyboard case CAD data](cad/cg56.dxf)

MDF was cut by laser using this data.  Small holes are used to position each
piece using wooen tooth picks.  Some file works were applied to round the edges
and paper plaster was used to fill uneven surfaces.  So the resulting keyboard
case has a smooth shape.

NC LASER cut MDF board pieces were stacked and glued to form the keyboard case
which holds multiple Gateron-made Cherry-type mechanical switches.  Since
TEENSY 2.0++ was slightly bigger than the original target TEENSY 2.0, MDF case
was grooved to create enough space in it.

## Wiring of MCU

The MCU board is placed on the back of the Q-key with its top surface facing
downward with keyboard case in normal orientation.  When wiring MCU with
keyboard case flipped, the MCU board is placed on the back of the Q-key with
its top surface facing upward from the flipped keyboard case.

Top view of Teensy 2.0++ board:

```
                              Q-key
                              MINI
                              USB
                        +---+-----+---+
                    GND |*  |     |  *|Vcc
                    PB7 |*  |     |  *|PB6
                    PD0 |*  |     |  *|PB5
                    PD1 |*  +-----+  *|PB4
                    PD2 |*           @|PB3    1 MISO
                    PD3 |*           @|PB2    4 MOSI
                    PD4 |*           @|PB1    3 SCLK
                    PD5 |*           *|PB0
              (LED) PD6 |*           *|PE7
                    PD7 |*           *|PE6
                    PE0 |*           *|GND
                    PE1 |*           *|AREF
                    PC0 |*           *|PF0
                    PC1 |*           *|PF1
                    PC2 |*           *|PF2
                    PC3 |*           *|PF3
                    PC4 |*           *|PF4
                    PC5 |*           *|PF5
                    PC6 |*           *|PF6
                    PC7 |*   @ @ @   *|PF7
                        +-------------+
                             ^ ^ ^
                             | | |
        VCC 2 ---------------+ | |
        GND 6 -----------------+ |
        RST 5 -------------------+
```
The pin names used here are ones for AT90USB1286 chip.

Here, the Teensy2.0++ board has:
* 43 total PINs (easily accessible outer ones)
* 7 non-IO PINs
* 36 I/O pins  --- This is the advantage too.

There are 31 I/O needs under normal usage:
* 8 rows of keyboard switches (input)
* 7 columns of keyboard switches (output)
* 8 LEDs of keyboard (output)
* 1 internal LED
* 1 Speaker (output)
* 6 dedicated ISP programming (B1, B2, B3, VCC, GND, RST)

This can be implemented as:

* `DIODE_DIRECTION COL2ROW (Column as input side)
* `ROW[0:7] =      { B7, D0, D1, D2, D3, D4, D5, D7 }` (write) - Cathode
* `Column[0:6] =   { E0, E1, C0, C1, C2, C3, C4 }`     (read) - Anode
* `LED[1:4][R:B] = { B6, B5, F4, F5, F6, F7, C5, C7 }`
  `                  QR  QB                  PB  PR`
* Internal_LED =  { D6 }
* Sound[0] =      { C6 } (OCR3A, Timer 3, channel A, 16 bits)

This ensures access to reprogram via SPI/ISP/ICSP using AVR-ISP II by keeping
all the following pins available as input if keys are not pressed.

* B1 SCLK
* B2 MOSI
* B3 MISO
*    RESET

Also this leaves all PF-pins for analog I/O.

(Reset should have pull-up resister 10K ???)

#### MCU to Parts

For easier wiring, let's recap as a counter clockwise mapping for the MCU
board. (MCU under Q-Key, far side first):

The pin names usage here are ones for AT90USB1286 chip.

Pin order from USB connector side:

* Anti-clock wise: Top view
* Clock wise: Bottom view

| MCU | Parts | Note |I/O|
|-----|---|---|---|
| GND | GND | * * | |
| PB7 | R0 | `Q`-row | O |
| PD0 | R2 | `A`-row | O |
| PD1 | R4 | `Z`-row | O |
| PD2 | R6 | left-bottom-row | O |
| PD3 | R1 | `P`-row | O |
| PD4 | R3 | `;`-row | O |
| PD5 | R5 | `/`-bottom row | O |
| PD6 | | Internal LED | O |
| PD7 | R7 | right-bottom row | O |
| PE0 | C0 | `Tab/]`-column | I |
| PE1 | C1 | `Q/Y`-column | I |
| PC0 | C2 | `W/U`-column | I |
| PC1 | C3 | `E/I`-column | I |
| PC2 | C4 | `R/O`-column | I |
| PC3 | C5 | `T/P`-column | I |
| PC4 | C6 | `[/BS`-column | I |
| PC5 | LED4R | `P`-side LED BLUE | O |
| PC6 | SPEAKER | SPEAKER | O |
| PC7 | LED4B | `P`-side LED RED | O |
| VCC | VCC | * * | * |
| GND | GND | * * | O |
| RST | RST | * * | * |
| PF7 | LED | `Y`-side LED | O |
| PF6 | LED | `Y`-side LED | O |
| PF5 | LED | `T`-side LED | O |
| PF4 | LED | `T`-side LED | O |
| PF3 | A? | | |
| PF2 | A? | | |
| PF1 | A? | | |
| PF0 | A? | | |
| Aref| A? | | |
| GND | | | |
| PE6 | | | O |
| PE7 | | | O |
| PB0 | | | O |
| PB1 | SCLK | * * | O |
| PB2 | MOSI | * * | O |
| PB3 | MISO | * * | O |
| PB4 | | | O |
| PB5 | LED1B | `Q`-side LED BLUE | O |
| PB6 | LED1R | `Q`-side LED RED | O |
| VCC | NC | * * | |

PF-pins will be used for joystick (optional).

micro-USB (female) on PCB to mini-USB (male) conversion is created by cutting
mini-USB-cable and using micro-USB pitch converter PCB.

USB wire color inside cable:

* RED -- `USB VCC (5V)`
* GREEN -- `D+`
* WHITE -- `D-`
* BLACK -- `GND`

#### MCU firmware

Please note that the generic Teensy 2.0++ bought at Aliexpress/bangood are just
PCB pattern copy product which doesn't come with the proprietary Teensy
firmware by pjrc.com.

First thing to do is flash your AT90USB1286 chip with the LUFA HID bootloader
by connecting the programmer via SPI interface using `avrdude` program.  Any
SPI interface programmer can be used.  The LUFA HID bootloader is a good choice
and takes 4KB space for the bootloader.

Connection to ISP is done with IC clip directly to the board. (no connector)

See https://osamuaoki.github.io/jp/2021/12/11/atmega32u4-4/

### LED

Follow the GH60 LED code example for simplicity for 8 GPIO PINs in which
simple on/off control is applied to the anodes of the LEDs with their
cathodes grounded.  Use CRD (18mA) between Teensy output and Anode of each
LED.  Please note total current limitation limits only 4 of them can be on at
once.

User can redefine one of the following `__attribute__ ((weak))` functions
to customize LED behavior:

* `led_set_user`
* `led_set_kb`
* `led_set`

USB control the following mode LED

* Numeric lock:
* Caps Lock:
* Scroll lock:

### Guide for the wiring steps

1. Test MCU board by programming via AVR-ISP with blink LED on PD6.

1. LEDs are lightly glued with hot-melt glue to the key switches to prevent
   falling.

1. All 56 key switches are placed into the keyboard case.  I used hot-melt glue
   to hold loose switches.  Please don't overdo it.  You can always add more
   glue after everything is completed to ensure the mechanical integrity of the
   keyboard.

1. Then the wiring of rows are done.  Adjacent row pins are connected with 24mm
   cut ETFE wire of AWG30 (0.26mmD) with each end stripped about 2mm.  Wire are
   passed through inside cavity of the case so it doesn't interfere with the
   bottom cap plate of the case.

1. Then the wiring of columns are done.  Line marked anode side of diodes are
   always connected to the key switches.  Cathode side with bar are connected
   within each column. (Column to row configuration)

1. Use tester to check keyboard connections in ohm mode.  (Please note that, in
   ohm mode of modern multimater, diode appears as insulator for both
   directions.)

1. Use tester to check forward and reverse voltage drop across each diode to be
   around 0.5V-0.6V and OL (overrange) to make sure each diode pointing the
   right direction and not shorted.  It is easy to overlook the cathode
   marking.

1. Connect MCU board to parts.

1. Place PI tape underneath the MCU, speaker and connector positions to prevent
   shorting the circuit and mark proper MCU position aligning with the bottom
   cap.  Watch for VCC(5V), output pins and circuit around USB connector.

1. Secure position of MCU with the hot-melt glue to the case.

1. Glue micro-USB female connector on PCB to the case.  (This has a short male
   mini-USB plug soldered)

1. Connect mini-USB connector to MCU board.

1. If keyboard functions perfectly, close the bottom plate.

## BOM

The following reference prices are rough US$ figures for the baseline
estimates.  Expect to drop about $150 which is more than a typical gaming
mechanical keyboards.  It ain't cheap but it's fun!!!

* 1 x Teensy 2.0++ compatible (banggood)  --  $15
* 1 x Mini-USB cable - comes with Teensy2.0
* Lasser cut 3mm MDF board              --  $50 (Japanese local company)
* Gateron Brown 87 switches (ebay)      --  $30
* Blank PBT 87 keycaps (ebay)           --  $20
* LED                                   --  $ 5
* CRD                                   --  $ 5
* Speaker (Piezo Transducer)            --  $ 1
* Diode IN4148 equiv. (100 piece pack)  --  $ 2
* AWG30 multi color set                 --  $ 5
* Hot melt glue and glue gun            --  $10 (?)
* Solders, circuit tester, ...

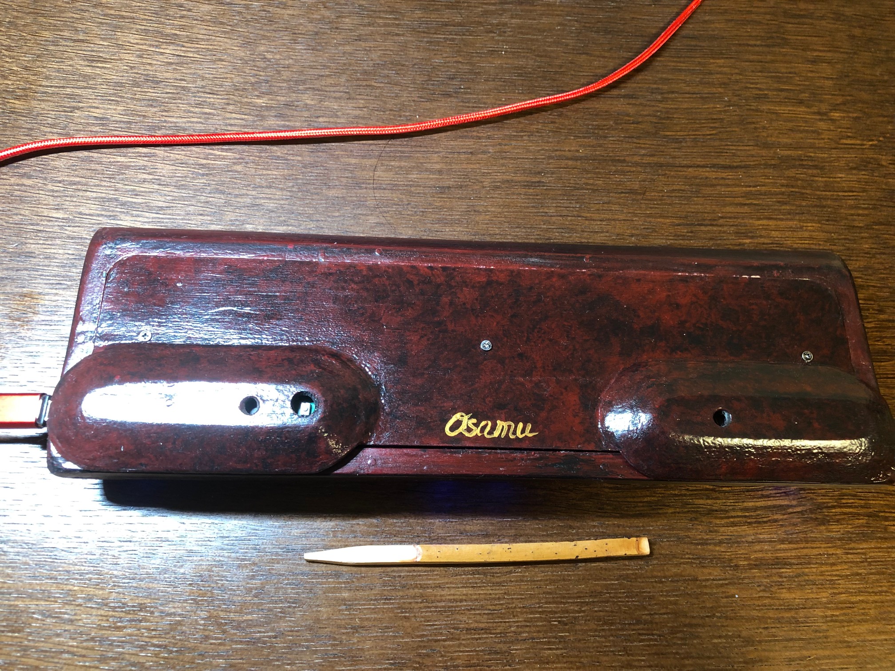
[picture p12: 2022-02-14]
img/cgc56-below.jpg

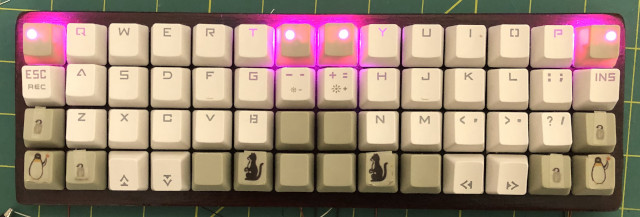
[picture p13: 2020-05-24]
img/kbdtop.jpeg

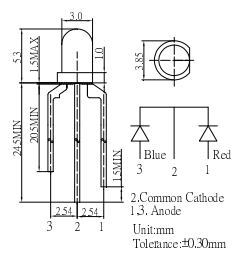
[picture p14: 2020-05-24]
img/OSRB3132A.png

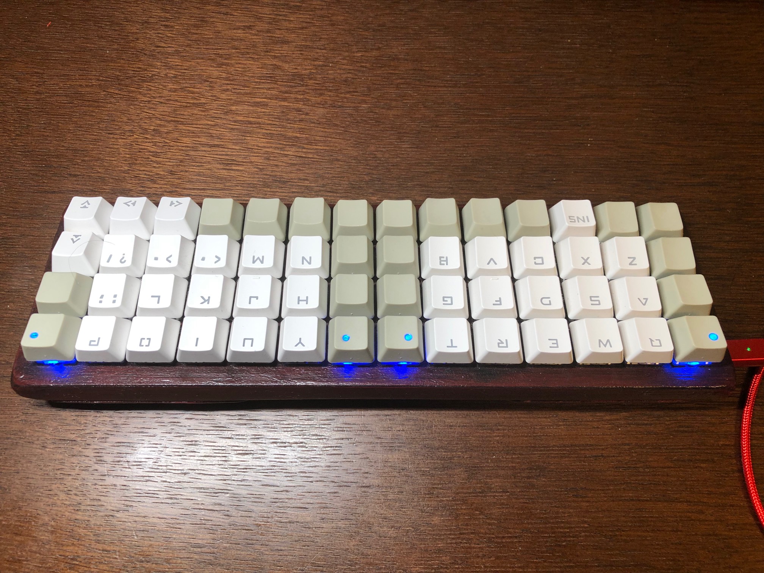
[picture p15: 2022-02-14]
img/cgc56-back.jpg

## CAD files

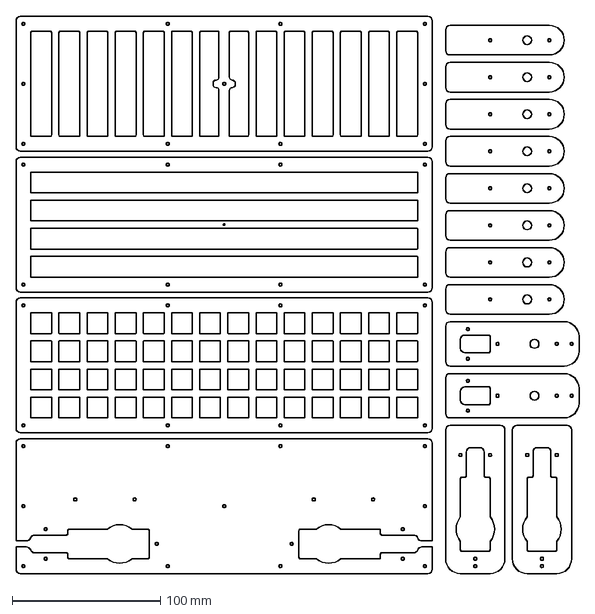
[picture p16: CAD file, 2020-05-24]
cad/cg56.dxf
380.0 x 376.0 mm

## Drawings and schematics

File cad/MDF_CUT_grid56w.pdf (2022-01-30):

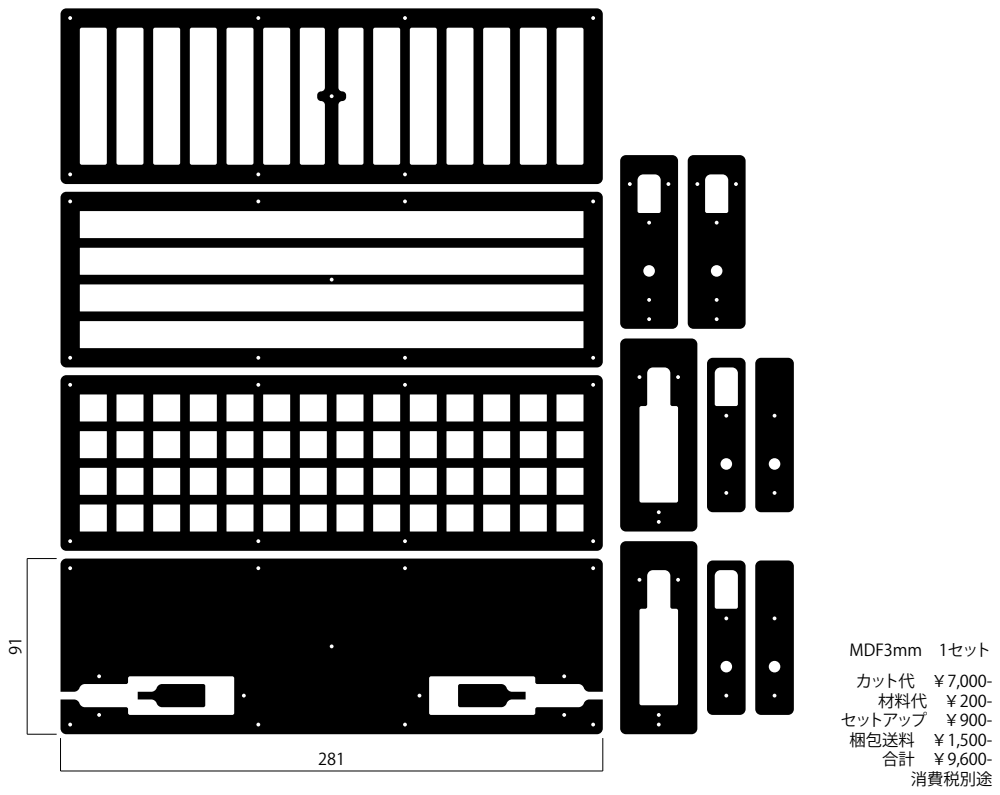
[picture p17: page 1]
カット代 ￥7,000- 材料代 ￥200- セットアップ ￥900- 梱包送料 ￥1,500- 合計 ￥9,600- 消費税別途; MDF3mm 1セット

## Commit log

2020-05-24 Restart cg56 repo
    [cg56.dxf]
2022-01-30 Add PDF for MDF case
